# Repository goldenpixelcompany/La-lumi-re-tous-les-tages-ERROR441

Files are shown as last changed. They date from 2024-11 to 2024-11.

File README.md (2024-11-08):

# La lumière à tous les étages : ERROR 441
*Manuel pour allumer la lumière à tous les étages*

Voici un manuel pour apprendre à allumer la lumière à tous les étages. Et ce n’est pas toujours évident. Surtout lorsque les étages sont longs et grands et que la nature nous attribue une petite taille. Je fais un mètre soixante-neuf et j’avais besoin d’aide. Pour accomplir ma mission, je dû me faire une amie. Mais cette amie n’existait pas et nous l’avons inventée avec d’autres amis.

**Partie I : dispositif**

Nous avons choisi de réaliser cette experience à lécole des arts décoratifs de Paris. Nous étions nombreux à vouloir accomplir cette mission. Voici le batiment concerné avant et après la lumière allumée : 
facade01

Composée de 441 fenêtres d’un mètre sur un mètre vingt, la baie vitrée de l'école s’étale sur 25 mètres de haut et 21 mètres de large. Chaque fenêtre se transformerait en pixel à l'aide d'un dispositif numérique composé de Leds RGB et de papier. Tous ces dispositifs sont connectés ensembles et forment un écran dit micro-géant : Immense par ses dimensions et minuscule par sa résolution.
Plan de travail 1

**Partie II : Hardware**

Pour connecter ces oixels entre eux, nous avons développer un circuit électronique adapté. Chacun d'entre eux controllait 3 pixels. Nous appelions donc les circuits les *métapixels*. Il y avait 147 circuits tous connectés en WIFI et commander par la puce ESP32. Le voici : 

pcb01

**Partie III : Software**

Pour controller cet écran de pixels géant nous avons developpé le software *SEND PIX*. Essentiellement developpé par Lorris Sahli, le logiciel est à la croisée d'un outil de dessin, de gestion de pixels et d'un instrument de VJing en direct. 

screen_02

Résultat des animations dessinées par le logiciel SEND PIX : 
Capture d’écran 2024-10-24 à 10 55 39

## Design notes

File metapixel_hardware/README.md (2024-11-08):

# metapixel

PCB made for control the pixels on the facade. By three they come.

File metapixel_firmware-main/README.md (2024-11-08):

# Metapixel firmware

This is code contains firmware codes for ESP32-WROOM for the intsllation. 
Protocole used : MQTT to declare their ID (assignation) and Artnet to manage LED control. 

## upload on macos

- Install pio-cli : https://docs.platformio.org/en/stable/core/index.html

- Go to repo : metapixel _firmware and run command `pio run -t upload`

- On mac it is possible to have this error : A fatal error occurred: Failed to write to target RAM (result was 01070000: Operation timed out)

- To dodge this error you need to install CH34 DRIVER on : https://www.wch.cn/downloads/CH34XSER_MAC_ZIP.html

- then type : `ls /dev/cu*` and you will see 'yourdevice'+wchusbserial552E0075671

- Then type your upload command : `pio run -t upload --upload-port /dev/cu.wchusbserial552E0075671` (target your new port)

- Upload should succeed !

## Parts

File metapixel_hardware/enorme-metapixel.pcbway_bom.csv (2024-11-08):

 |  |  | T-I210W48185A 170PCS BOM (Bill of Materials)
Item # | *Designator | *Qty | Manufacturer | *Mfg Part # | Description / Value | *Package/Footprint | Type | Your Instructions / Notes
1 | C1 | 1 |  |  | 1µF 5V | C_0603_1608Metric | SMD | do use this exact part. LCSC # C150119
2 | C3, C4 | 2 | Murata Electronics | GRM188R6YA106MA73D | 10µF 35V X5R | C_0603_1608Metric | SMD | do use this exact part. LCSC # C150120
3 | C5, C11 | 2 | CCTC | TCC0603X7R104K500CT | 100nF 50V X7R | C_0603_1608Metric | SMD | do use this exact part. LCSC # C150121
4 | C6 | 1 | YAGEO | CC0603KRX7R9BB333 | 33nF 50V X7R | C_0603_1608Metric | SMD | do use this exact part. LCSC # C150122
5 | C7 | 1 | CCTC | TCC0402X5R104M250AT | 0.1µF 25V X5R | C_0402_1005Metric | SMD | do use this exact part. LCSC # C150123
6 | C8, C9, C2 | 3 | Chinocera | HGC0603R5226M100NTHJ | 22µF 10V X5R | C_0603_1608Metric | SMD | do use this exact part. LCSC # C150124
7 | D1 | 1 | XINGLIGHT | XL-1608UBC-04 | USER LED BLUE | LED_0603_1608Metric | SMD | do use this exact part. LCSC # C150125
8 | L1 | 1 | SHOU HAN | CYA0650-6.8UH | 6.8µH | L_Bourns_SRP7028A_7.3x6.6mm | SMD | do use this exact part. LCSC # C150126
9 | Q1, Q2, Q3, Q4, Q5, Q6, Q7, Q8, Q9 | 9 | TOSHIBA | SSM3K329R | SSM3K329R | SOT-23 | SMD | do use this exact part. LCSC # C150127
10 | R1, R2, R3, R4, R5, R6, R7, R8, R9 | 9 |  |  | 100K | R_0603_1608Metric | SMD
11 | R10, R11 | 2 |  |  | 10K | R_0603_1608Metric | SMD
12 | R12, R13, R14, R15, R16, R17, R18, R19, R20, R21 | 10 |  |  | 1K | R_0603_1608Metric | SMD
13 | R22 | 1 |  |  | 5R 5% | R_0603_1608Metric | SMD
14 | R23 | 1 |  |  | 10K 1% | R_0603_1608Metric | SMD
15 | R24 | 1 |  |  | 52.3K 1% | R_0603_1608Metric | SMD
16 | SW1 | 1 | PANASONIC | EVQQ2U03W | SW_RESET | EVQQ2 | SMD | do use this exact part. LCSC # C701204
17 | SW2 | 1 | PANASONIC | EVQQ2U03W | SW_BOOT | EVQQ2 | SMD | do use this exact part. LCSC # C701204
18 | U1 | 1 | STMicroelectronics | LDL1117S33R | LDL1117-3.3 | SOT-223-3_TabPin2 | SMD | do use this exact part. LCSC # C435835
19 | U2 | 1 | Espressif Systems | ESP32-WROOM-32-N4 | ESP32-WROOM-32 | ESP32-WROOM-32 | SMD | do use this exact part. LCSC # C82899
20 | U3 | 1 | TPS62933DRLR | TPS62933DRLR | TPS62933DRLR | SOT-583-8 | SMD | do use this exact part. LCSC # C3200405
21 | H1 | 1 | do not place | do not place | M4 | MountingHole_4.3mm_M4 | DNS / DNP | do not place / do not buy
22 | H2 | 1 | do not place | do not place | PEG | MountingHole_3.2mm_M3 | DNS / DNP | do not place / do not buy
23 | J1, J6 | 2 | do not place | do not place | VIN | bornier-2_P5.08mm | DNS / DNP | do not place / do not buy
24 | J2 | 1 | do not place | do not place | STRIP_0 | PLUG_Terminal_01x04_2.54mm | DNS / DNP | do not place / do not buy
25 | J3 | 1 | do not place | do not place | STRIP_1 | PLUG_Terminal_01x04_2.54mm | DNS / DNP | do not place / do not buy
26 | J4 | 1 | do not place | do not place | STRIP_2 | PLUG_Terminal_01x04_2.54mm | DNS / DNP | do not place / do not buy
27 | J5 | 1 | do not place | do not place | UART | PinHeader_1x04_P2.54mm_Vertical | DNS / DNP | do not place / do not buy

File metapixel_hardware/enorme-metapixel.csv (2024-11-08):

Reference | Value | Footprint | Datasheet | Farnell | LCSC | MFR | Qty
C1 | 1µF 5V | Capacitor_SMD:C_0603_1608Metric | ~ | 3188840 |  |  | 1
C2 | 22µF | Capacitor_SMD:C_0805_2012Metric | ~ | 3013461 | C7432770 |  | 1
C3, C4 | 10µF 35V X5R | Capacitor_SMD:C_0603_1608Metric | ~ |  | C194427 |  | 2
C5, C11 | 100nF 50V X7R | Capacitor_SMD:C_0603_1608Metric | ~ |  | C282519 |  | 2
C6 | 33nF 50V X7R | Capacitor_SMD:C_0603_1608Metric | ~ |  | C106856 |  | 1
C7 | 0.1µF 25V X5R | Capacitor_SMD:C_0402_1005Metric | ~ |  | C359190 |  | 1
C8, C9 | 22µF 10V X5R | Capacitor_SMD:C_0603_1608Metric | ~ |  | C7432770 |  | 2
D1 | USER LED BLUE | LED_SMD:LED_0603_1608Metric | ~ |  | C965807 | XL-1608UBC-04 | 1
H1 | M4 | MountingHole:MountingHole_4.3mm_M4 | ~ |  |  | do not place | 1
H2 | PEG | MountingHole:MountingHole_3.2mm_M3 | ~ |  |  | do not place | 1
J1, J6 | VIN | ENSADLED:fiche_bornier-2_P5.08mm | ~ |  |  | do not place | 2
J2 | STRIP_0 | ENSADLED:PLUG_Terminal_01x04_2.54mm | ~ |  |  | do not place | 1
J3 | STRIP_1 | ENSADLED:PLUG_Terminal_01x04_2.54mm | ~ |  |  | do not place | 1
J4 | STRIP_2 | ENSADLED:PLUG_Terminal_01x04_2.54mm | ~ |  |  | do not place | 1
J5 | UART | Connector_PinHeader_2.54mm:PinHeader_1x04_P2.54mm_Vertical | ~ |  |  | do not place | 1
L1 | 6.8µH | Inductor_SMD:L_Bourns_SRP7028A_7.3x6.6mm | ~ |  | C5189755 | CYA0650-6.8UH | 1
Q1-Q9 | SSM3K329R | Package_TO_SOT_SMD:SOT-23 | https://fr.farnell.com/3872284 | 3872284 | C150127 | SSM3K329R | 9
R1-R9 | 100K | Resistor_SMD:R_0603_1608Metric | ~ |  |  |  | 9
R10, R11 | 10K | Resistor_SMD:R_0603_1608Metric | ~ |  |  |  | 2
R12-R21 | 1K | Resistor_SMD:R_0603_1608Metric | ~ |  |  |  | 10
R22 | 5R 5% | Resistor_SMD:R_0603_1608Metric | ~ |  |  |  | 1
R23 | 10K 1% | Resistor_SMD:R_0603_1608Metric | ~ |  |  |  | 1
R24 | 52.3K 1% | Resistor_SMD:R_0603_1608Metric | ~ |  |  |  | 1
SW1 | SW_RESET | ENSADLED:EVQQ2 | ~ |  | C701204 | EVQQ2U03W | 1
SW2 | SW_BOOT | ENSADLED:EVQQ2 | ~ |  | C701204 | EVQQ2U03W | 1
U1 | LDL1117-3.3 | Package_TO_SOT_SMD:SOT-223-3_TabPin2 | https://www.diodes.com/assets/Datasheets/AZ1117.pdf |  | C435835 | LDL1117S33R | 1
U2 | ESP32-WROOM-32 | RF_Module:ESP32-WROOM-32 | https://www.espressif.com/sites/default/files/documentation/esp32-wroom-32_datasheet_en.pdf |  | C82899 | ESP32-WROOM-32-N4 | 1
U3 | TPS62933DRLR | Package_TO_SOT_SMD:SOT-583-8 | https://www.ti.com/lit/ds/symlink/tps62933.pdf |  | C3200405 | TPS62933DRLR | 1

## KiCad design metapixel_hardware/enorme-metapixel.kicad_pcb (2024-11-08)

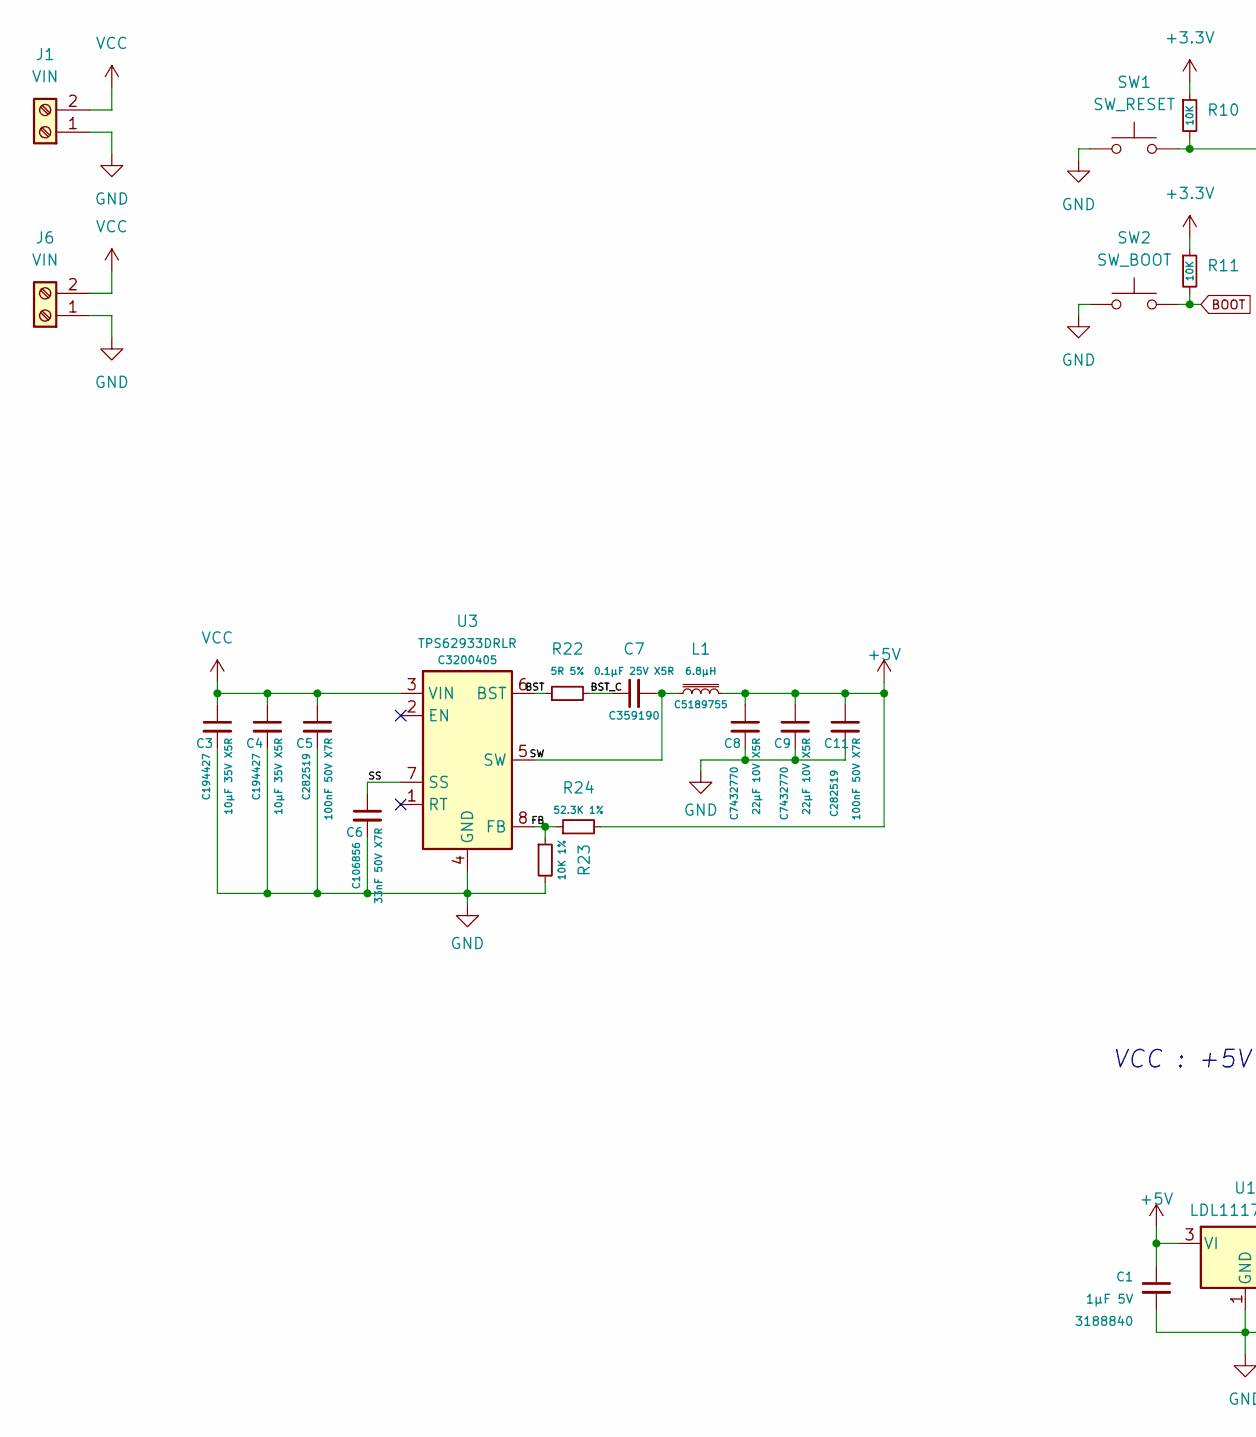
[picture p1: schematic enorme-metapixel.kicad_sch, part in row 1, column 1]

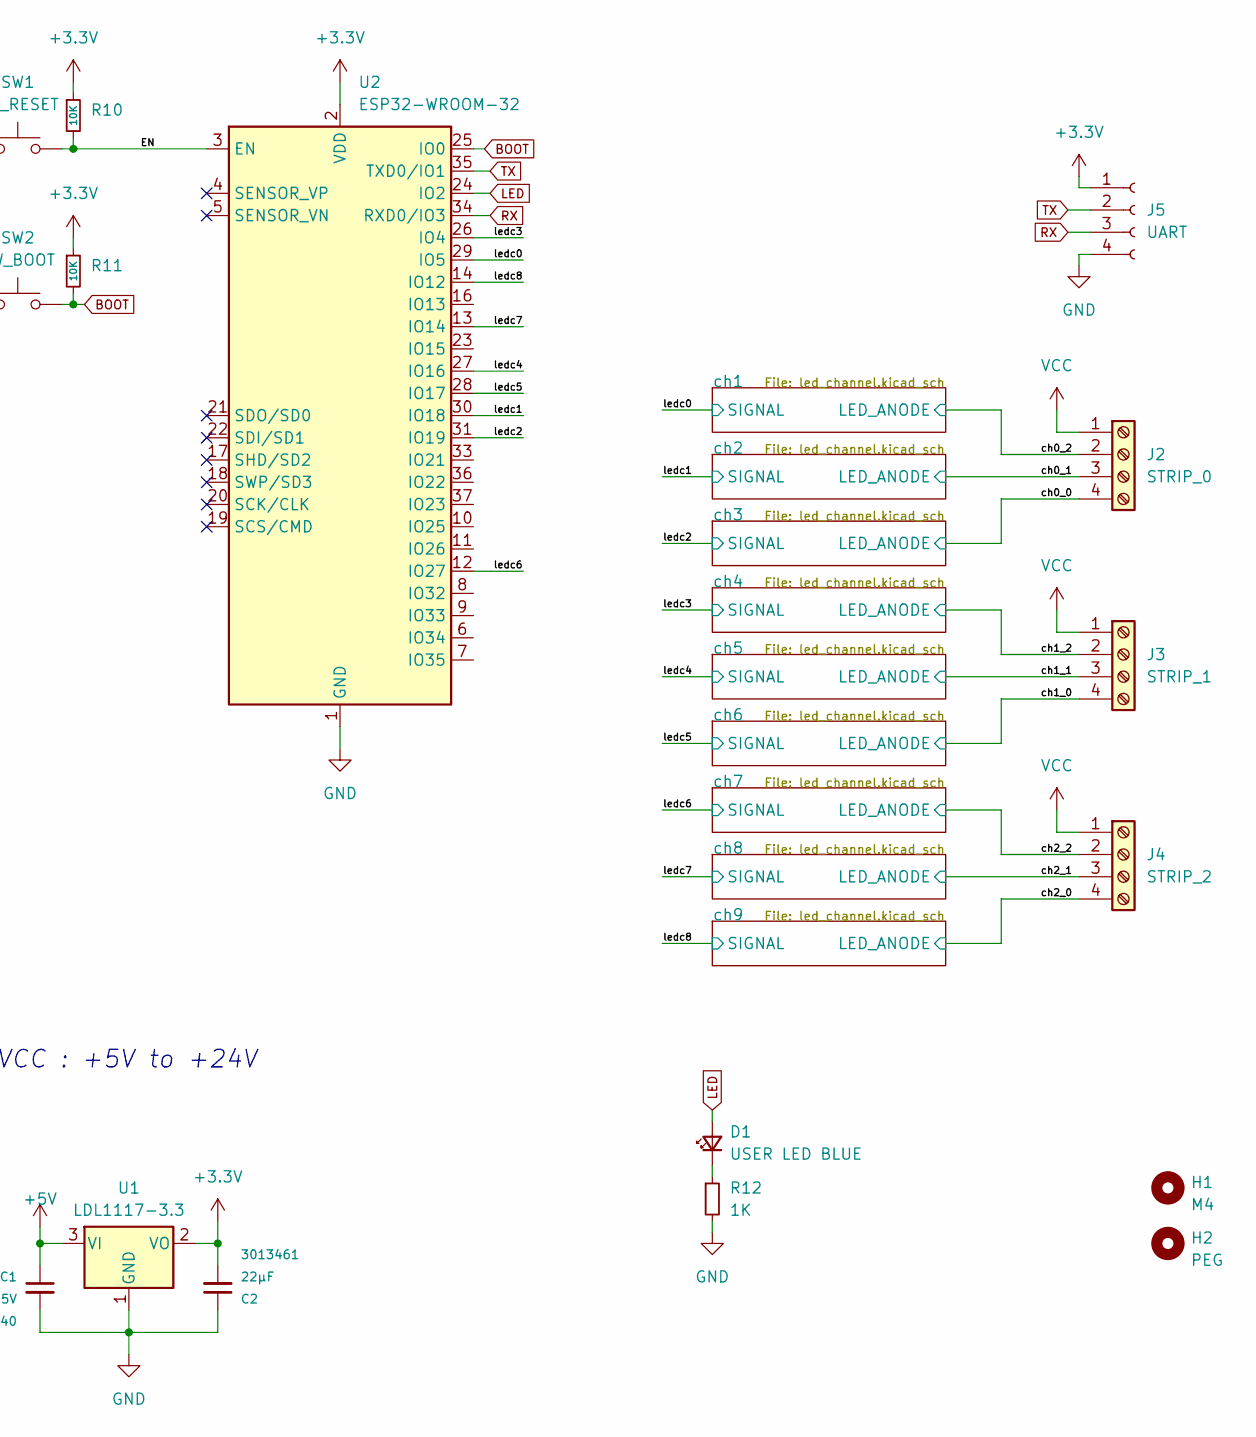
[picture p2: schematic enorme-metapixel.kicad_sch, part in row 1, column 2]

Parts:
C1: 1µF 5V; C_0603_1608Metric; Farnell 3188840
C2: 22µF; C_0805_2012Metric; Farnell 3013461
C3, C4: 10µF 35V X5R; C_0603_1608Metric; LCSC C194427
C5, C11: 100nF 50V X7R; C_0603_1608Metric; LCSC C282519
C6: 33nF 50V X7R; C_0603_1608Metric; LCSC C106856
C7: 0.1µF 25V X5R; C_0402_1005Metric; LCSC C359190
C8, C9: 22µF 10V X5R; C_0603_1608Metric; LCSC C7432770
D1: USER LED BLUE; LED_0603_1608Metric; LCSC C965807
H1: M4; MountingHole_4.3mm_M4
H2: PEG; MountingHole_3.2mm_M3
J1, J6: VIN; fiche_bornier-2_P5.08mm
J2: STRIP_0; PLUG_Terminal_01x04_2.54mm
J3: STRIP_1; PLUG_Terminal_01x04_2.54mm
J4: STRIP_2; PLUG_Terminal_01x04_2.54mm
J5: UART; PinHeader_1x04_P2.54mm_Vertical
L1: 6.8µH; L_Bourns_SRP7028A_7.3x6.6mm; LCSC C5189755
R10, R11: 10K; R_0603_1608Metric
R12: 1K; R_0603_1608Metric
R22: 5R 5%; R_0603_1608Metric
R23: 10K 1%; R_0603_1608Metric
R24: 52.3K 1%; R_0603_1608Metric
SW1: SW_RESET; EVQQ2; LCSC C701204
SW2: SW_BOOT; EVQQ2; LCSC C701204
U1: LDL1117-3.3; SOT-223-3_TabPin2; LCSC C435835
U2: ESP32-WROOM-32; LCSC C82899
U3: TPS62933DRLR; SOT-583-8; LCSC C3200405

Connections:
+3.3V: C2.2, J5.1, R10.1, R11.1, U1.2 (VO), U2.2 (VDD)
+5V: C1.1, C8.1, C9.1, C11.1, L1.2, R24.2, U1.3 (VI)
/BST: R22.1, U3.6 (BST)
/BST_C: C7.1, R22.2
/EN: R10.2, SW1.2, U2.3 (EN)
/FB: R23.1, R24.1, U3.8 (FB)
/SS: C6.1, U3.7 (SS)
/SW: C7.2, L1.1, U3.5 (SW)
/ch0_0: J2.4; also elsewhere on the board
/ch0_1: J2.3; also elsewhere on the board
/ch0_2: J2.2; also elsewhere on the board
/ch1_0: J3.4; also elsewhere on the board
/ch1_1: J3.3; also elsewhere on the board
/ch1_2: J3.2; also elsewhere on the board
/ch2_0: J4.4; also elsewhere on the board
/ch2_1: J4.3; also elsewhere on the board
/ch2_2: J4.2; also elsewhere on the board
/ledc0: U2.29 (IO5); also elsewhere on the board
/ledc1: U2.30 (IO18); also elsewhere on the board
/ledc2: U2.31 (IO19); also elsewhere on the board
/ledc3: U2.26 (IO4); also elsewhere on the board
/ledc4: U2.27 (IO16); also elsewhere on the board
/ledc5: U2.28 (IO17); also elsewhere on the board
/ledc6: U2.12 (IO27); also elsewhere on the board
/ledc7: U2.13 (IO14); also elsewhere on the board
/ledc8: U2.14 (IO12); also elsewhere on the board
BOOT: R11.2, SW2.2, U2.25 (IO0)
GND: C1.2, C2.1, C3.2, C4.2, C5.2, C6.2, C8.2, C9.2, C11.2, J1.1, J5.4, J6.1, R12.2, R23.2, SW1.1, SW2.1, U1.1 (GND), U2.1 (GND), U2.15 (GND), U2.38 (GND), U2.39 (GND), U3.4 (GND); also elsewhere on the board
LED: D1.2 (A), U2.24 (IO2)
unnamed: D1.1 (K), R12.1
RX: J5.3, U2.34 (RXD0/IO3)
TX: J5.2, U2.35 (TXD0/IO1)
VCC: C3.1, C4.1, C5.1, J1.2, J2.1, J3.1, J4.1, J6.2, U3.3 (VIN)

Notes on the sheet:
VCC : +5V to +24V

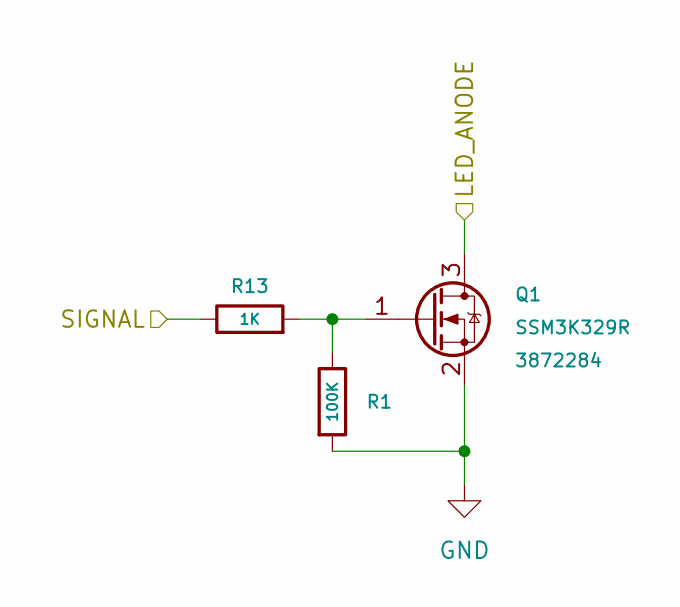
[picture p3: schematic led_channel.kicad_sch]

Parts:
Q1: SSM3K329R; SOT-23; Farnell 3872284
R1: 100K; R_0603_1608Metric
R13: 1K; R_0603_1608Metric

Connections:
/ch0_2: Q1.3 (D); also elsewhere on the board
/ledc0: R13.1; also elsewhere on the board
GND: Q1.2 (S), R1.2; also elsewhere on the board
unnamed: Q1.1 (G), R1.1, R13.2

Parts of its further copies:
Q2, Q3, Q4, Q5, Q6, Q7, Q8, Q9: SSM3K329R; SOT-23; Farnell 3872284
R2, R3, R4, R5, R6, R7, R8, R9: 100K; R_0603_1608Metric
R14, R15, R16, R17, R18, R19, R20, R21: 1K; R_0603_1608Metric

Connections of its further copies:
/ch0_0: Q3.3 (D); also elsewhere on the board
/ch0_1: Q2.3 (D); also elsewhere on the board
/ch1_0: Q6.3 (D); also elsewhere on the board
/ch1_1: Q5.3 (D); also elsewhere on the board
/ch1_2: Q4.3 (D); also elsewhere on the board
/ch2_0: Q9.3 (D); also elsewhere on the board
/ch2_1: Q8.3 (D); also elsewhere on the board
/ch2_2: Q7.3 (D); also elsewhere on the board
/ledc1: R14.1; also elsewhere on the board
/ledc2: R15.1; also elsewhere on the board
/ledc3: R16.1; also elsewhere on the board
/ledc4: R17.1; also elsewhere on the board
/ledc5: R18.1; also elsewhere on the board
/ledc6: R19.1; also elsewhere on the board
/ledc7: R20.1; also elsewhere on the board
/ledc8: R21.1; also elsewhere on the board
GND: Q2.2 (S), Q3.2 (S), Q4.2 (S), Q5.2 (S), Q6.2 (S), Q7.2 (S), Q8.2 (S), Q9.2 (S), R2.2, R3.2, R4.2, R5.2, R6.2, R7.2, R8.2, R9.2; also elsewhere on the board
unnamed: Q2.1 (G), R2.1, R14.2
unnamed: Q3.1 (G), R3.1, R15.2
unnamed: Q4.1 (G), R4.1, R16.2
unnamed: Q5.1 (G), R5.1, R17.2
unnamed: Q6.1 (G), R6.1, R18.2
unnamed: Q7.1 (G), R7.1, R19.2
unnamed: Q8.1 (G), R8.1, R20.2
unnamed: Q9.1 (G), R9.1, R21.2

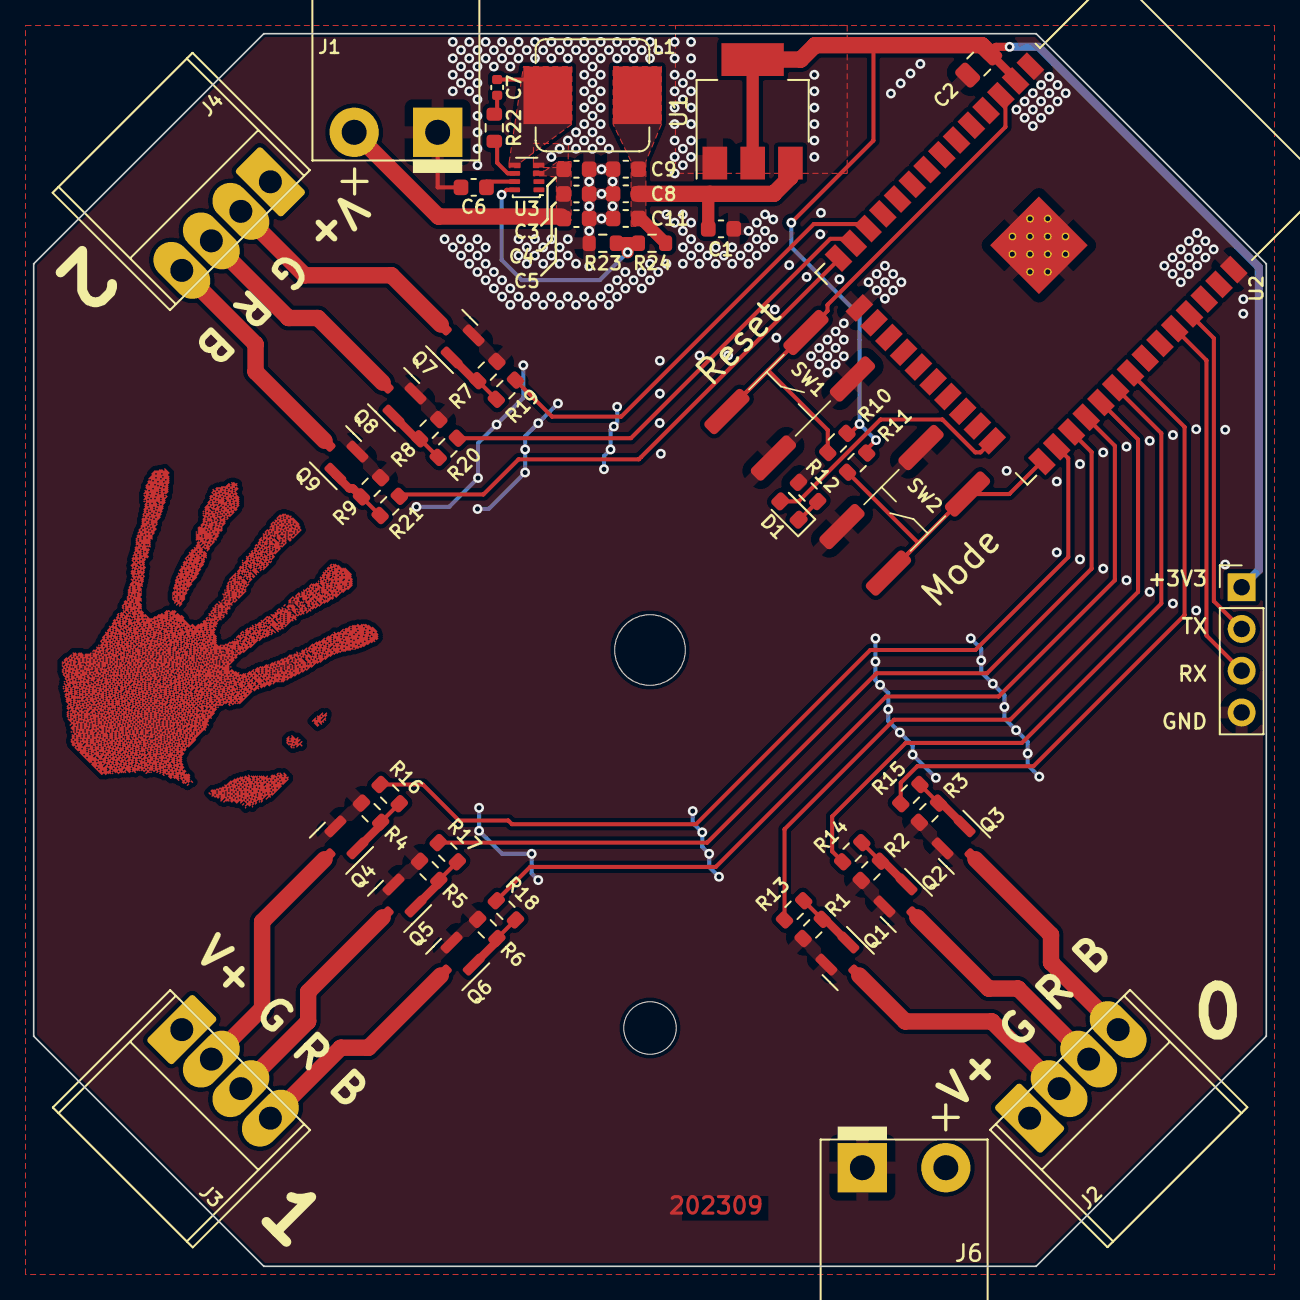
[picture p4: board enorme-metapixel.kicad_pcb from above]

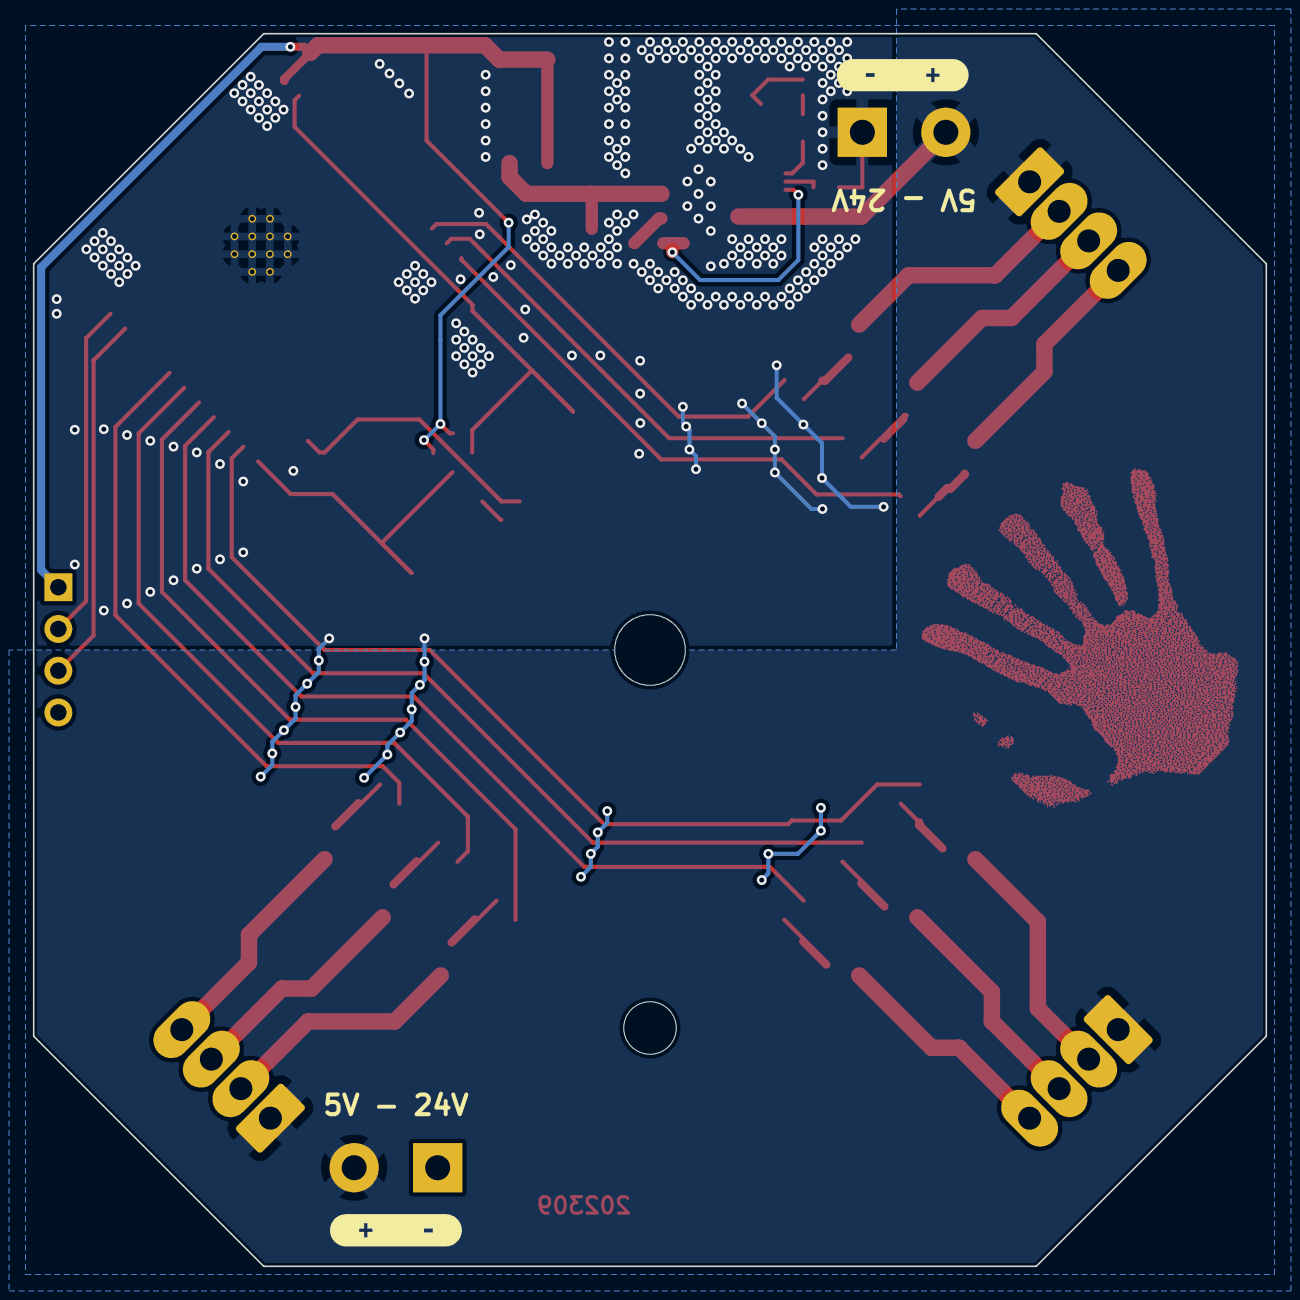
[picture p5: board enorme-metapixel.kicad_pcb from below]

Board: 2 copper layers, 75.0 x 75.0 mm, 60 parts (2 on the bottom side), 42 nets.

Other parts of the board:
kibuzzard-63B86E3D, kibuzzard-63B86E3D#2: G***; kibuzzard-63B86E3D

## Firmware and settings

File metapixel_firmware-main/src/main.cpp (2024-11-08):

#define WIFI_TIMEOUT_FOULE 30000
#define WIFI_TIMEOUT_ENSAD 30000

#define HEARTBEAT_LOW 1000
#define HEARTBEAT_HIGH 5000

#define SSID_FOULE "FOULE_LED"
#define PSK_FOULE  "Bijahouix"

#define SSID_ENSAD "ENSAD-LED"
#define PSK_ENSAD  "Lmdpdeensadled"

#define DEFAULT_UNIVERSE 1
#define START_ADDR 1

#include <Arduino.h>
#include <esp_task_wdt.h>
#include <Preferences.h>
Preferences preferences;

#define BAUDRATE 115200
#define LOOP_INTERVAL 1  // global loop interval in ticks

// Network stack
#include <WiFi.h>
#include <ESPmDNS.h>
#include <ArduinoOTA.h>
#define OTA_PASS "Bijahouix"

char host[22];

// App
#include <ArtnetWifi.h>
ArtnetWifi artnet;

uint16_t frame_count = 0;

uint16_t univ_a = 1;
uint16_t univ_b = 1;
uint16_t univ_c = 1;

uint16_t addr_a = 0;
uint16_t addr_b = 0;
uint16_t addr_c = 0;

uint32_t colormult_r = 65535;
uint32_t colormult_g = 65535;
uint32_t colormult_b = 65535;

uint32_t brightness = 32768;

uint32_t master = 65535;

uint8_t framerate = 25;

uint8_t do_save = false;

#include "backend.h"
#include "led_helper.h"

bool running = true;
uint8_t mode = MODE_ARTNET;



uint8_t buffer [NUM_CHANNEL];
uint32_t next_out = 0;

void loop_out(void * _){
    while(true){
        if(millis() >= next_out){
            next_out = millis() + 1000/framerate;
            for (int i = 0; i < NUM_CHANNEL; ++i){
                setCalibratedChannel(i, buffer[i]);
            }
        }
        vTaskDelay(1);
    }
    vTaskDelete(NULL);
}

void out_sync(){
    next_out = 0;
}

void testMode(){
    for (int i = 0; i < NUM_CHANNEL; ++i){
        ledcWrite(i, gamma28_8b_16b[(millis()/10)%200]);
    }
}

void whiteMode(){
    for (int i = 0; i < NUM_CHANNEL; ++i){
        setCalibratedChannel(i, 255);
    }
}

void blackMode(){
    for (int i = 0; i < NUM_CHANNEL; ++i){
        setCalibratedChannel(i, 0);
    }
}

void idleMode(){
    for (int i = 0; i < NUM_CHANNEL; ++i){
        setCalibratedChannel(i, 10);
    }
}

void fill_in(uint8_t channel, uint8_t value){
    buffer[channel] = value;
}

void on_artnet(uint16_t universe, uint16_t length, uint8_t sequence, uint8_t* data){

    if(mode == MODE_ARTNET){
        uint16_t starts[3] =  {addr_a, addr_b, addr_c};
        uint16_t univs[3] =  {univ_a, univ_b, univ_c};

        for (int px = 0; px < 3; ++px){
            if(universe == univs[px]){
                for (int i = 0; i < 3; ++i){
                    fill_in(
                        (px*3)+i,
                        data[starts[px]+i]
                    );
                }
            }
        }   
    }

    ledcWrite(9, gamma28_8b_16b[frame_count*10]);
    frame_count ++;
    frame_count = frame_count % 25;
}

// front end loop
void loop_metapixel(void * _){

    ledcAttachPin(LED_BUILTIN, 9);
    ledcSetup(9, PWM_FREQ, PWM_RES_BITS);

    artnet.setArtDmxCallback(on_artnet);
    artnet.begin();

	delay(10);

	while(running){
		if(artnet.read() == ART_SYNC){
            Serial.println("sync");
        }
        switch(mode){
            case MODE_IDLE:
                idleMode();
            break;
            case MODE_WHITE:
                whiteMode();
            break;
            case MODE_BLACK:
                blackMode();
            break;
            case MODE_ARTNET:
                // handled elsewhere
            break;
            default:
            break;
        }
        vTaskDelay(1);
        /*taskYIELD();
        esp_task_wdt_reset();*/
	}
    vTaskDelete(NULL);
}

void setupOSC(){

    preferences.begin("MPX", false); 

    univ_a = preferences.getUInt("univ_a", univ_a);
    univ_b = preferences.getUInt("univ_b", univ_b);
    univ_c = preferences.getUInt("univ_c", univ_c);

    addr_a = preferences.getUInt("addr_a", addr_a);
    addr_b = preferences.getUInt("addr_b", addr_b);
    addr_c = preferences.getUInt("addr_c", addr_c);

    colormult_r = (uint32_t)preferences.getUInt("colormult_r", colormult_r);
    colormult_g = (uint32_t)preferences.getUInt("colormult_g", colormult_g);
    colormult_b = (uint32_t)preferences.getUInt("colormult_b", colormult_b);

    brightness = (uint32_t)preferences.getUInt("brightness", brightness);
    framerate = (uint8_t)preferences.getUInt("framerate", framerate);

    OscWiFi.subscribe(OSC_IN_PORT, "/addresses", addr_a, addr_b, addr_c);
    OscWiFi.subscribe(OSC_IN_PORT, "/universes", univ_a, univ_b, univ_c);
    OscWiFi.subscribe(OSC_IN_PORT, "/calibration", colormult_r, colormult_g, colormult_b);
    OscWiFi.subscribe(OSC_IN_PORT, "/brightness", brightness);
    OscWiFi.subscribe(OSC_IN_PORT, "/mode", mode);
    OscWiFi.subscribe(OSC_IN_PORT, "/master", master);

    OscWiFi.subscribe(OSC_IN_PORT, "/save", do_save);

    OscWiFi.subscribe(OSC_IN_PORT, "/framerate", framerate);

    OscWiFi.subscribe(OSC_IN_PORT, "/sync", [](){
        out_sync();
    });

    OscWiFi.subscribe(OSC_IN_PORT, "/restart", [](){
        ESP.restart();
    });

}

void setup() {
	pinMode(LED_BUILTIN, OUTPUT);
    digitalWrite(LED_BUILTIN, HIGH);
	pinMode(PIN_BTN, INPUT);

	// build and set hostname
	uint64_t mac = ESP.getEfuseMac();
    uint64_t reversed_mac = 0;

    for (int i = 0; i < 6; i++) {
        reversed_mac |= ((mac >> (8 * i)) & 0xFF) << (8 * (5 - i));
    }

    snprintf(host, 22, "MPX-%llX", reversed_mac);

    delay(100);
    Serial.begin(BAUDRATE);
    delay(400);
    Serial.println(host);
    Serial.println(VERSION_STRING);

    setupWiFi();
    setupOTA();
    setupLED();

    setupOSC();

    xTaskCreatePinnedToCore(
        loop_metapixel,   // Function that should be called
        "Metapixel",      // Name of the task (for debugging)
        20000,            // Stack size (bytes)
        NULL,             // Parameter to pass
        1,                // Task priority
        NULL,             // Task handle
        !xPortGetCoreID() // pin to not the one running this
    );

    xTaskCreatePinnedToCore(
        loop_out,         // Function that should be called
        "Out",            // Name of the task (for debugging)
        20000,            // Stack size (bytes)
        NULL,             // Parameter to pass
        10,               // Task priority
        NULL,             // Task handle
        !xPortGetCoreID() // pin to not the one running this
    );

    delay(10);

    digitalWrite(LED_BUILTIN, LOW);

    Serial.println(broadcastAddress);
}

void save_prefs(){
    preferences.putUInt("univ_a", univ_a);
    preferences.putUInt("univ_b", univ_b);
    preferences.putUInt("univ_c", univ_c);

    preferences.putUInt("addr_a", addr_a);
    preferences.putUInt("addr_b", addr_b);
    preferences.putUInt("addr_c", addr_c);

    preferences.putUInt("colormult_r", (uint16_t)colormult_r);
    preferences.putUInt("colormult_g", (uint16_t)colormult_g);
    preferences.putUInt("colormult_b", (uint16_t)colormult_b);

    preferences.putUInt("brightness", (uint16_t)brightness);

    preferences.putUInt("framerate", (uint16_t)framerate);
}

// backend loop
void loop(){
  // wifi
  if(WiFi.status() != WL_CONNECTED){
    ledcWrite(9, gamma28_8b_16b[255]);
    setupWiFi();
    broadcastAddress = (WiFi.localIP() | ~WiFi.subnetMask());
  }

  // OSC
  handle_osc();

  // OTA
  ArduinoOTA.handle();
  vTaskDelay(LOOP_INTERVAL);

  if(do_save > 0){
    do_save = 0;
    save_prefs();
  }
}

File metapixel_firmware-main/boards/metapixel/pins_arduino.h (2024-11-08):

#ifndef Pins_Arduino_h
#define Pins_Arduino_h

#include <stdint.h>

#define EXTERNAL_NUM_INTERRUPTS 16
#define NUM_DIGITAL_PINS        40
#define NUM_ANALOG_INPUTS       16

#define analogInputToDigitalPin(p)  (((p)<20)?(analogChannelToDigitalPin(p)):-1)
#define digitalPinToInterrupt(p)    (((p)<40)?(p):-1)
#define digitalPinHasPWM(p)         (p < 34)

static const uint8_t LED_BUILTIN = 2;
#define BUILTIN_LED  LED_BUILTIN // backward compatibility
#define LED_BUILTIN LED_BUILTIN

#define PIN_A_G 27
#define PIN_A_R 14
#define PIN_A_B 12

#define PIN_B_G 4
#define PIN_B_R 16
#define PIN_B_B 17

#define PIN_C_G 5
#define PIN_C_R 18
#define PIN_C_B 19

#define PIN_BTN 0


static const uint8_t TX = 1;
static const uint8_t RX = 3;

static const uint8_t SDA = 21;
static const uint8_t SCL = 22;

static const uint8_t SS    = 5;
static const uint8_t MOSI  = 23;
static const uint8_t MISO  = 19;
static const uint8_t SCK   = 18;

static const uint8_t A0 = 36;
static const uint8_t A3 = 39;
static const uint8_t A4 = 32;
static const uint8_t A5 = 33;
static const uint8_t A6 = 34;
static const uint8_t A7 = 35;
static const uint8_t A10 = 4;
static const uint8_t A11 = 0;
static const uint8_t A12 = 2;
static const uint8_t A13 = 15;
static const uint8_t A14 = 13;
static const uint8_t A15 = 12;
static const uint8_t A16 = 14;
static const uint8_t A17 = 27;
static const uint8_t A18 = 25;
static const uint8_t A19 = 26;

static const uint8_t T0 = 4;
static const uint8_t T1 = 0;
static const uint8_t T2 = 2;
static const uint8_t T3 = 15;
static const uint8_t T4 = 13;
static const uint8_t T5 = 12;
static const uint8_t T6 = 14;
static const uint8_t T7 = 27;
static const uint8_t T8 = 33;
static const uint8_t T9 = 32;

static const uint8_t DAC1 = 25;
static const uint8_t DAC2 = 26;

#endif /* Pins_Arduino_h */

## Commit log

2024-11-08 Code uplaoded
    [enorme-metapixel-B_Cu.gbl, enorme-metapixel-B_Mask.gbs, enorme-metapixel-B_Paste.gbp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]
2024-11-08 SEND PIX Uploaded
    [export_presets.cfg]
